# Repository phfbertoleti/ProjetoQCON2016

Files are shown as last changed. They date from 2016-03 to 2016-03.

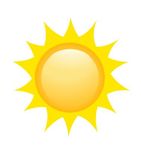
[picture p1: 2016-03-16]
Interface Web (com criptografia)/DIA.jpg

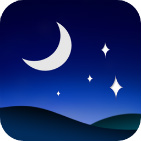
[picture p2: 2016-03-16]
Interface Web (com criptografia)/NOI.jpg

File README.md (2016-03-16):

# GitHub do projeto desenvolvido para a palestra "Embedded Systems e IoT: do bare-metal à comunicação wireless segura", realizada no evento QCON 2016.

Aqui, consta:

- Firmware completo do leitor de luminosidade (Arduino Nano v3.0)
- Firmware completo do leitor de temperatura (Arduino Duemilanove)
- Firmware completo do medidor de vazão instantânea e consumo acumulado de água (PIC)
- Script Python completo (Intel Edison)
- WebSocket que se comunica com Broker MQTT Mosquitto
- Perfis de configuração ZigBEE

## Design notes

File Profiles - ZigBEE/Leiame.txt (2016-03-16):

IMPORTANTE:

Ao carregar os perfis, não esquecer de inserir a mesma chave de encriptação nos end devices e coordenadores. Caso contrário, a comunicação encriptada não funcionará.

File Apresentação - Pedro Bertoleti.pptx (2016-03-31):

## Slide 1

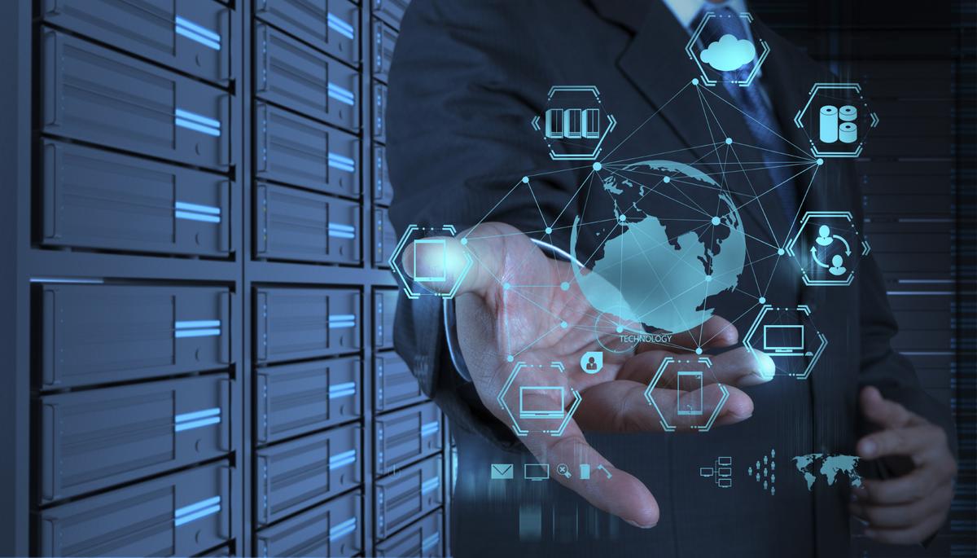
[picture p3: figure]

Embedded Systems e IoT: do bare-metal à comunicação wireless segura

Pedro Bertoleti

## Pedro Bertoleti

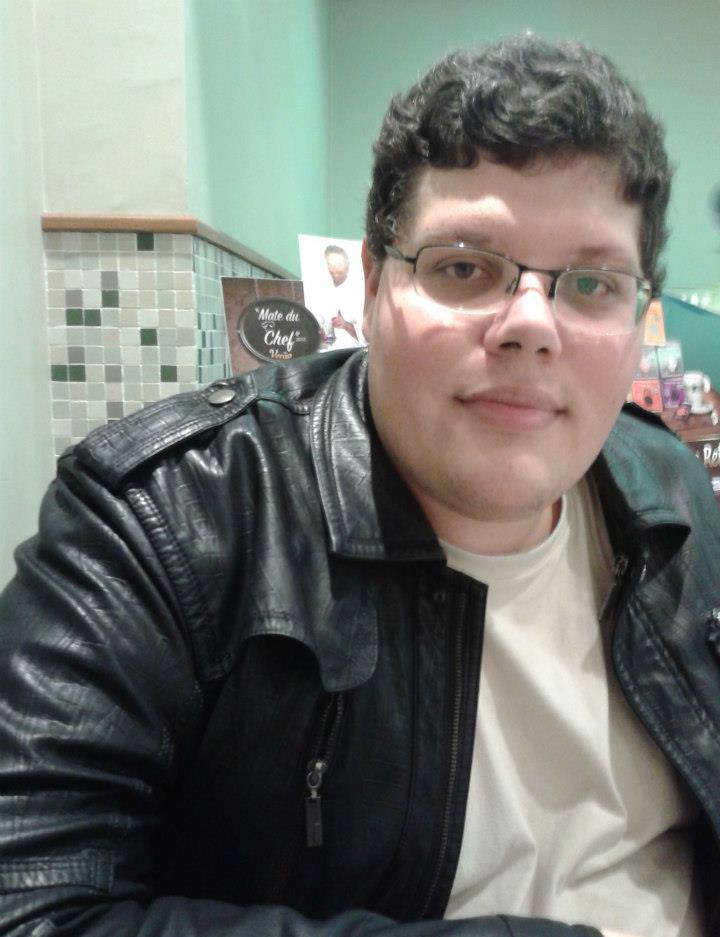
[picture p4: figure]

- Engenheiro eletricista
- Mais de 10 anos de experiência em Dev (incluindo sistemas embarcados)
- Engenheiro de firmware na Toledo do Brasil Ind. de Balanças
- Articulista do portal Embarcados (www.embarcados.com.br)

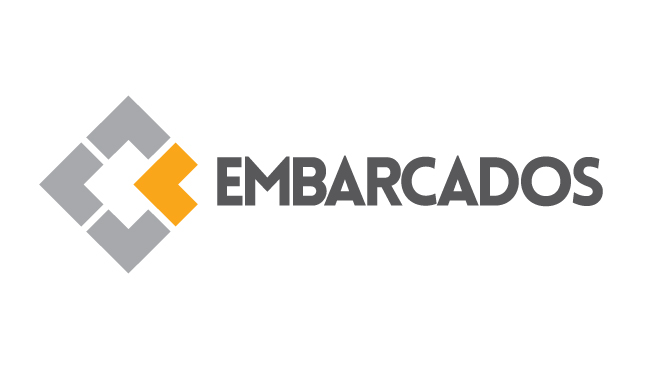
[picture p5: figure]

## Pedro Bertoleti

Áreas de interesse:
- Sistemas embarcados bare-metal
- Sensoriamento remoto
- IoT

## Tópicos desta palestra

- IoT e sensoriamento remoto
- Bare-metal no sensoriamento remoto
- O papel da Central / nó IoT
- Projeto-exemplo: arquitetura
- Projeto-exemplo: aquisição de dados
- Projeto-exemplo: publicação de dados
- Projeto-exemplo: segurança (hardware e software)
- Demonstração

## IoT

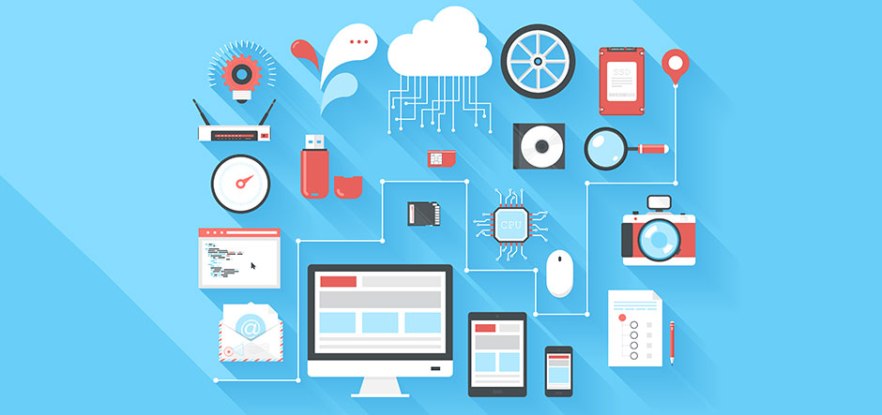
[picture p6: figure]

= tudo conectado a tudo!

## IoT

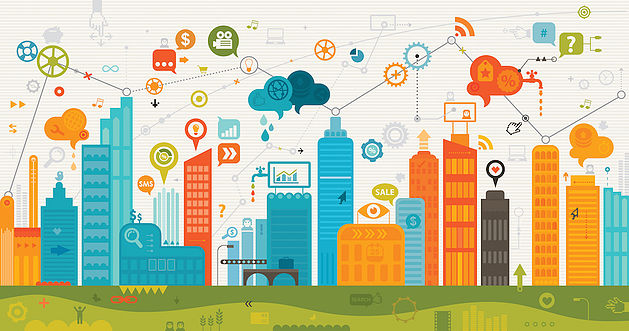
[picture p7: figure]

Então, porque não monitorar tudo, tonando nossas cidades e vidas mais inteligentes?

## IoT e sensoriamento remoto

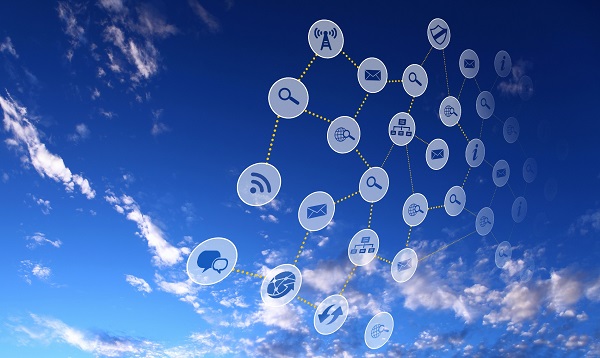
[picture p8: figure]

Para isso, é preciso sensoriar / medir tudo o que for possível!

## Caminho: Do bare-metal a IoT

Internet

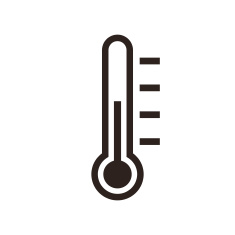
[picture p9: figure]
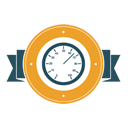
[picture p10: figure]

?

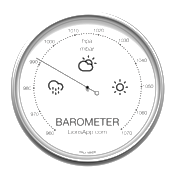
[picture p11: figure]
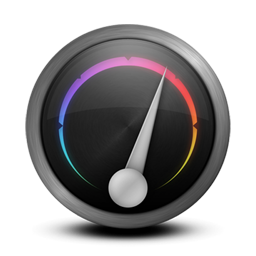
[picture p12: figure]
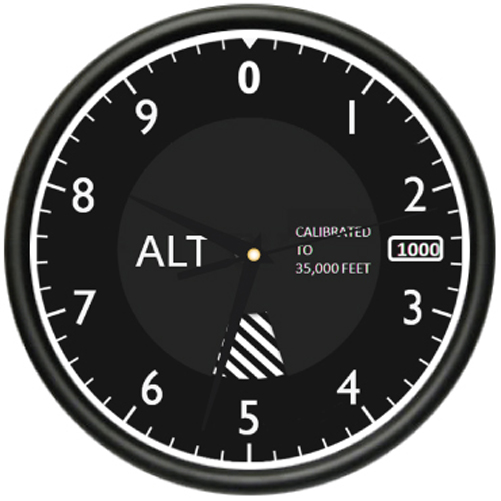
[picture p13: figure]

?

## IoT e sensoriamento remoto

Objetivos:
1) Qualidade de vida: monitorar grandezas de grande relevância financeira e ambiental

Exemplos: consumo de água, consumo de energia elétrica, poluição sonora, poluição atmosférica, etc.

2) Motivo comercial: formar uma base de dados para traçar comportamentos e tendências do consumidor

Exemplo: obter hora de pico de consumo de água e energia elétrica e suas variáveis relacionadas (temperatura ambiente, níveis de chuva, período do ano, ...) para, assim, conseguir melhor tarifar o uso destes recursos.

## IoT e sensoriamento remoto

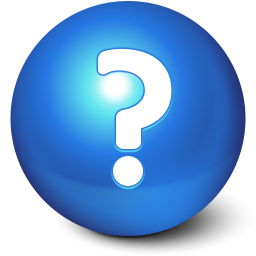
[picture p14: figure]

Como fazer?

## Bare-metal no sensoriamento remoto

Internet

Bare
Metal

?

## Bare-metal no sensoriamento remoto

O que é bare-metal?
- Modalidade de software embarcado “na raça” (sem S.O.)
- Linguagens envolvidas: C e Assembly (eventualmente C++)
- Usa o microcontrolador em baixo nível
- Permite a maior performance de um software embarcado
- Nesta camada, trabalha um desenvolvedor com maior experiência de back-end

## Bare-metal no sensoriamento remoto

Por que utilizar?
- Exige um microcontrolador com menos recursos
Permite uso de microcontroladores mais baratos (principalmente quanto a economia em memória Flash).
- Lida muito bem com grande número de interrupções sem comprometer performance final
- Maior número de proteções de software e hardware aplicáveis
Brown-out detection, Watchdog, saber o exato motivo de um reset, etc.
- Permite maior eficiência na comunicação com sensores (comunicação com periféicos de forma direta)
Funcionamento mais rápido e ágil.
- Software embarcado dedicado à sua aplicação
- Modalidade de software embarcado compatível com qualquer microcontrolador do mercado

## Bare-metal no sensoriamento remoto

Em suma:
- Permite o desenvolvimento de um software altamente robusto
- Permite uso de um hardware mais modesto
- Tem excelente performance e confiabilidade

Bare-metal: sistema projetado para ser ligado e esquecido (manutenção zero)

## O papel da Central / nó IoT

Internet

Bare
Metal

Central / Nó

## O papel da Central / nó IoT

Foi visto que:
- Fazer sensoriamento remoto é relevante tanto comercialmente quanto para aumento da qualidade de vida
- O sensoriamento começa no bare-metal
Mas, e para enviar estes dados para a Internet? O que fazer? Qual é o elo faltante?

## Central / nó IoT

- Nesta camada, o uso de um sistema operacional é bem vindo
Por baixo preço e alta disponibilidade de hardwares compatíveis e preço nulo de licença de uso, o Linux e suas distribuições mais compactas representa a maior parcela de S.O. embarcado.
- A central / nó IoT é capaz de se comunicar com sistemas bare-metal E comunicar-se com a Internet.
- É responsável por disponibilizar os dados lidos para a Internet de forma adequada.

## Central / nó IoT

- Aqui, trabalha um desenvolvedor com maior experiência de front-end
- Nesta camada, fala-se em IoT e derivados: MQTT, HTTP, Socket Connection, 3G/HSPDA/4G, etc.
- Pode ser ou não headless

## Projeto-exemplo

Internet

Consumo e fluxo de água

Luminosidade

Temperatura

Bare
Metal

Central / Nó

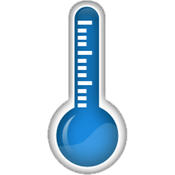
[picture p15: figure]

## Projeto-exemplo: arquitetura

Bare-metal

Consumo e fluxo de água

Bare-metal

Luminosidade

Bare-metal

Temperatura

Central-nó / IoT

Internet

Rede de sensoriamento com topologia em estrela

## Projeto-exemplo: arquitetura

- Protocolo de comunicação dos dispositivos sensores e central / nó IoT
[STX] [ENDEREÇO] [OPCODE] [TAMANHO] [CHECK-SUM] [BUFFER]
0x02 1 byte 1 byte 1 byte 1 byte Max. 255 bytes
Onde o Checksum é calculado por:
Checksum = (~SomaDeTodosOsBytes) + 1
- Os dados sempre são requisitados pela central IoT (ou seja, os módulos bare-metal funcionam sob demanda)
- Cada dispositivo de sensoriamento (bare-metal) possui um endereço

Dispositivo | Endereço
Medidor de água | 0x01
Medidor de luminosidade | 0x02
Medidor de temperatura | 0x03

Iternet

## Projeto-exemplo: arquitetura

- O sistema bare-metal comunica-se com a central IoT via ZigBEE (comunicação wireless), usando a encriptação AES 128-bit do próprio chip XBEE.
- A central IoT comunica-se com a Internet via MQTT, com payload encriptado em uma criptografia simétrica desenvolvida por mim.

Iternet

## Projeto-exemplo: aquisição de dados

- Medidor de água: calibração

Sinal do sensor de água

Conta os pulsos

Microcontrolador

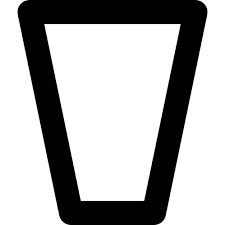
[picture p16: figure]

Volume de controle vazio

Início

Fim

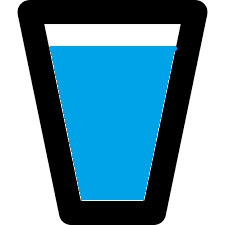
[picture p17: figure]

Iternet

Volume de controle cheio

## Projeto-exemplo: aquisição de dados

- Medidor de água: uso

Sinal do sensor de água

Microcontrolador

1- Conta os pulsos
2- Converte número de pulsos contados em volume
3- Calcula medições

## Projeto-exemplo: aquisição de dados

- Medidor de luminosidade: uso

Sinal do sensor de
luminosidade

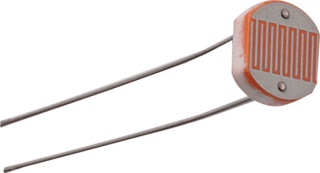
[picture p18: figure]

LDR
(sensor de luminosidade)

Microcontrolador

Converte leitura analógica em uma leitura relativa da luminosidade, capaz de dizer se é dia ou noite.

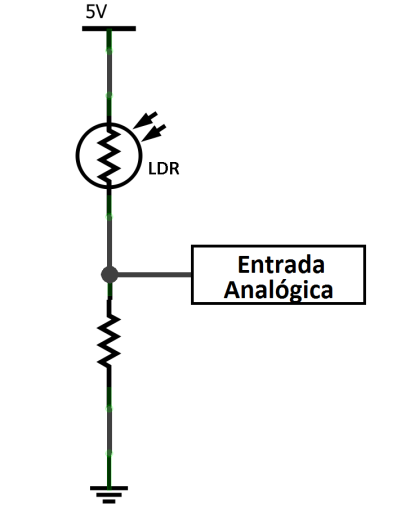
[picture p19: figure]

## Projeto-exemplo: aquisição de dados

- Medidor de temperatura: uso

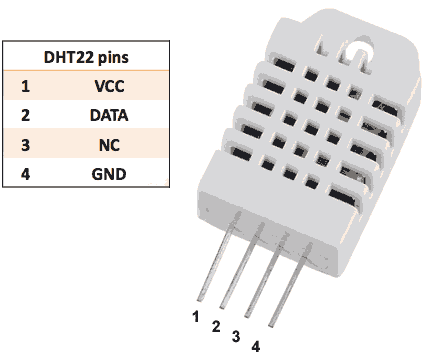
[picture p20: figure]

Protocolo de comunicação
síncrono

Microcontrolador

“Conversa” (através de um protocolo proprietário) com o sensor e obtém o valor da temperatura medida.

## Projeto-exemplo: publicação de dados

- A central IoT publica os dados para o mundo exterior via MQTT
- O payload é criptografado via criptografia proprietária
- Os dados enviados ao Broker são, necessariamente, interpretáveis somente por quem possui a chave certa de criptografia.
- No exemplo em questão, há uma maneira de modificar, quando desejado, a chave de criptografia

## Projeto-exemplo: publicação de dados

Central-nó / IoT

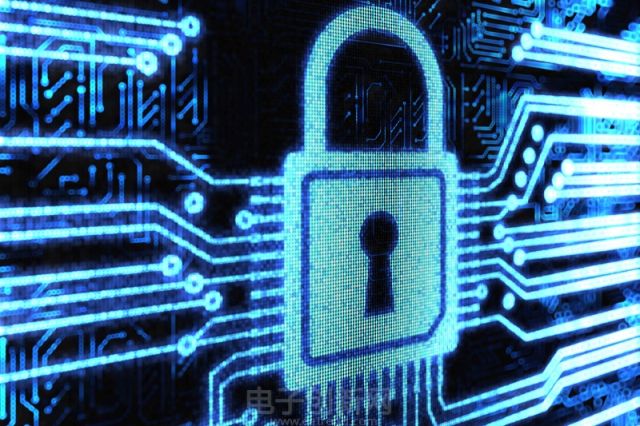
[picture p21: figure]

Criptografia simétrica proprietária

MQTT
(payload criptografado)

Internet

MQTT

Payload

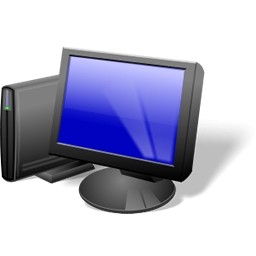
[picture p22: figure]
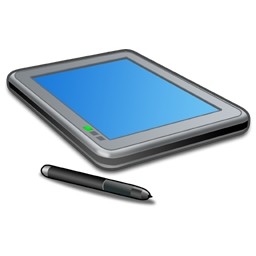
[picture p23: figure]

Dispositivos finais devem conhecer a chave para “entender” a informação

## Projeto-exemplo: segurança

Software
- Criptografia do payload (MQTT e da rede sensorial), com chave conhecida somente pelos elementos da comunicação (quem envia e quem recebe). Isso minimiza as chances de burlar a comunicação com sensores e com broker, garantindo que somente as partes interessadas terão acesso aos dados
- Os microcontroladores devem ter proteção contra leitura de código.
- A central IoT deve ter acesso restrito (atenção a senha de acesso root e sempre bloquear acesso via terminal serial / USB CDC nas placas de produção!!!)

## Projeto-exemplo: segurança

Hardware
- Não utilizar cartões SD para imagem do sistema da central-IoT. Utilizar EMC (equivalentes a memórias flash soldadas na placa).
- Após gravação dos softwares (seja no lado bare-metal ou central-IoT), colocar resina sobre os circuitos integrados principais (microcontroladores e memórias-flash)
- Somente colocar identificação de pontos de prova estitamente necessários (alimentação, por exemplo).
- Pintar a superfície dos circuitos integrados restantes (para dificultar identificação dos mesmos por alguém que queira clonar o hardware)
- Na etapa de produção, retirar todas as interfaces seriais de comunicação e debug utilizadas no desenvolvimento.
- Utilizar cases prensados para comportar as placas

## Demonstração

Acesse agora o site da demonstração!!
http://www.pjapps.qlix.com.br/QCONSP2016/

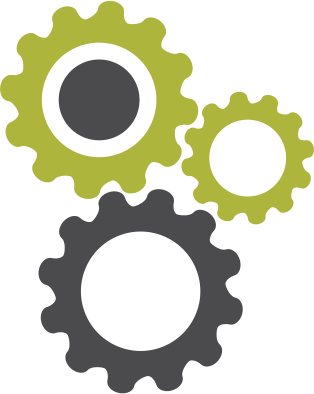
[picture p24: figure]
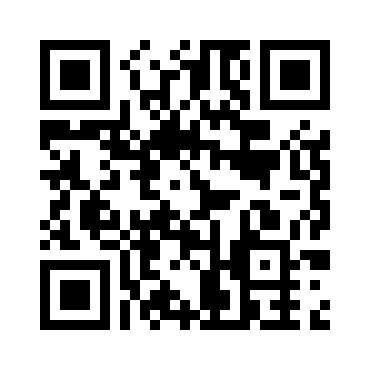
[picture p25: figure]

Iternet

## Download / colaboração do projeto

- GitHub: https (https://github.com/phfbertoleti/ProjetoQCON2016)://github.com/phfbertoleti/ProjetoQCON2016

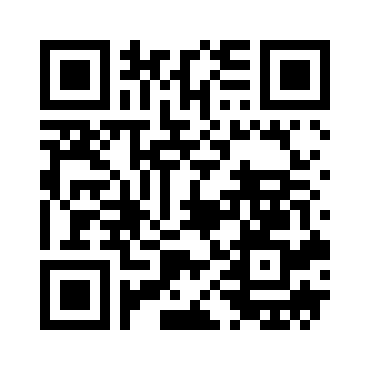
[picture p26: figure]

Iternet

## Final da palestra

Muito obrigado pela presença!

Facebook.com/pedro.bertoleti

@pedro_bertoleti

Pedro Bertoleti

In embedded we trust!

Iternet

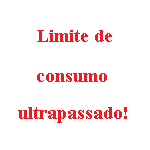
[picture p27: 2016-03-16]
Interface Web (com criptografia)/naook.png

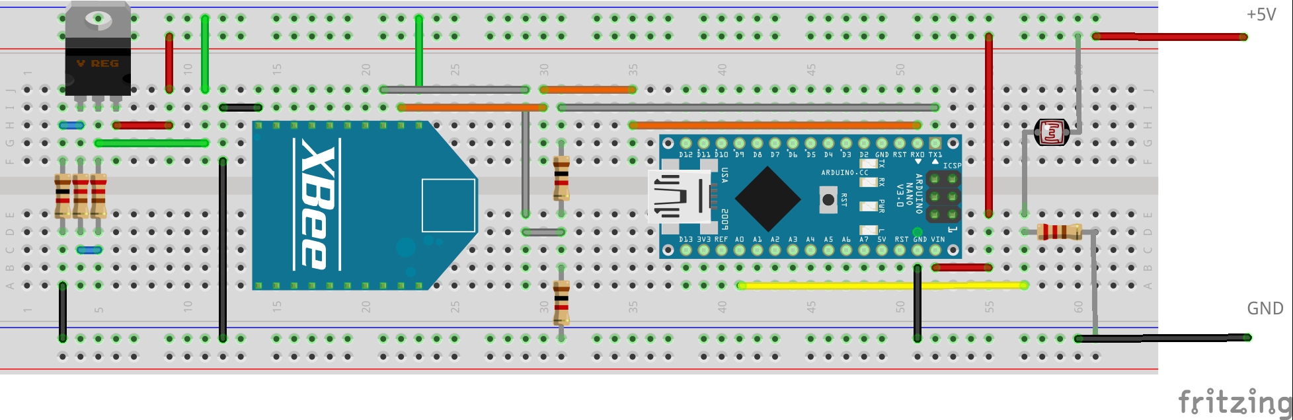
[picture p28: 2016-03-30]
Esquemáticos/Leitor de luminosidade/LeitorLuminosidade_esquematico.jpg

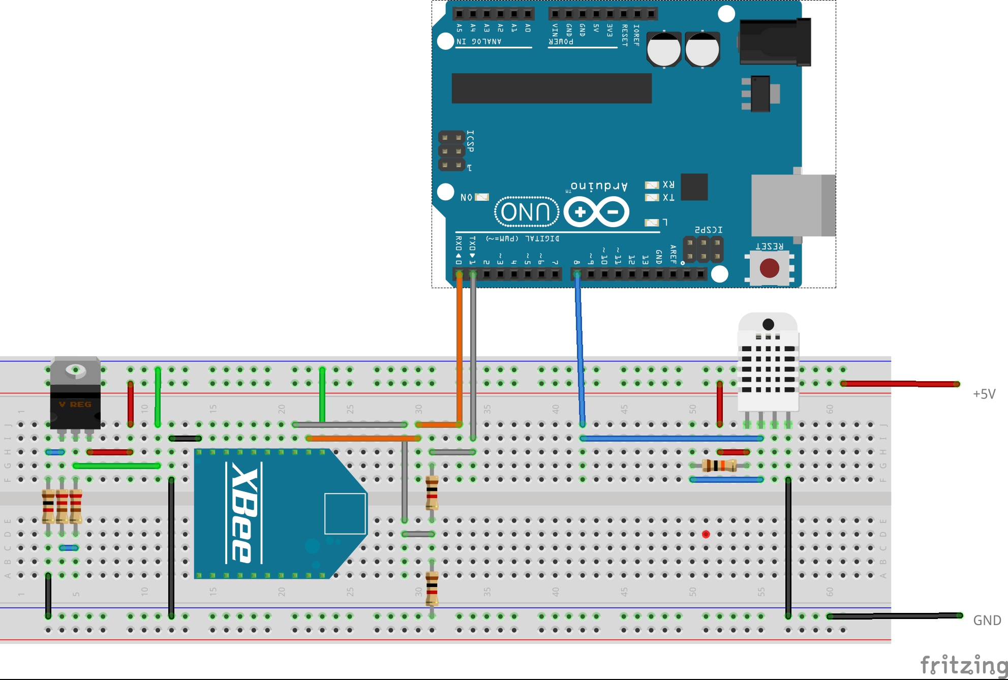
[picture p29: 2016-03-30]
Esquemáticos/Leitor de temperatura/LeitorTemperatura_esquematico.jpg

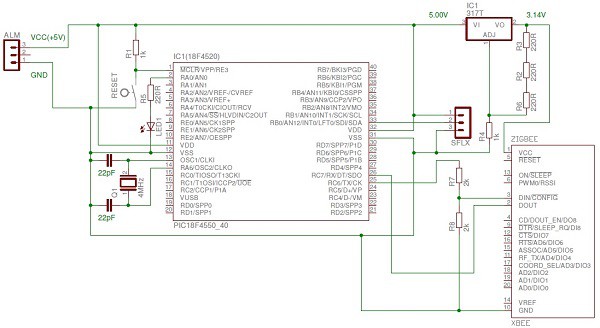
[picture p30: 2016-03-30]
Esquemáticos/Monitoramento - água/esquematico_monitoramento_agua.jpg

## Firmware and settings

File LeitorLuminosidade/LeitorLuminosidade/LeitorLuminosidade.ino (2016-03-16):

//Software do leitor de luminosidade (demonstração da palestra 
//"Embedded Systems e IoT: do bare-metal à comunicação wireless segura", 
//realizado no QCON 2016).
//Autor: Pedro Bertoleti
//Data: 02/2016
//
//IMPORTANTE: este software funciona tanto com shield ZigBEE
//            quanto com o ZigBEE ligado diretamente a serial


//----------------
// Defines gerais
//----------------
#define VERSAO               "V1.00"
#define TAMANHO_VERSAO       5
#define TAMANHO_LUMINOSIDADE 3
#define ENDERECO_BAREMETAL   2
#define SIM                  1
#define NAO                  0
#define DIA                  "DIA"
#define NOITE                "NOI"

//defines do protocolo
#define MAX_TAM_BUFFER    20
#define STX               0x02
#define CHECKSUM_OK       1
#define FALHA_CHECKSUM    0
#define RECEPCAO_OK       1
#define SEM_RECEPCAO      0

//defines dos estados
#define ESTADO_STX        1
#define ESTADO_ENDERECO   2
#define ESTADO_OPCODE     3
#define ESTADO_TAMANHO    4
#define ESTADO_CHECKSUM   5
#define ESTADO_BUFFER     6

//defines dos opcodes do protocolo (para sensor de luminosidade)
#define OPCODE_LEITURA_LUMINOSIDADE    'L'
#define OPCODE_VERSAO                  'V'

//define - tamanho da mensagem de resposta
#define TAMANHO_MAX_MSG_RESPOSTA        10 //8 bytes = STX (1 byte) + Endereço (1 byte) + Opcode (1 byte) + tamanho (1 byte) + checksum (1 byte) + Buffer (5 bytes)

//define - pino de leitura analógica
#define PINO_SENSOR_LUMINOSIDADE   0 //usa analog pin 0

//define - valor máximo que o ADC retorna na leitura
#define VALOR_MAX_ADC              1023

//----------------
// Estruturas / 
// typedefs
//----------------
typedef struct
{	
    char Endereco;
    char Opcode;
    char TamanhoMensagem;						
    char CheckSum;					
    char Buffer[MAX_TAM_BUFFER];					
} TDadosProtocoloLeitorLuminosidade;

//----------------
// variáveis globais
//----------------
TDadosProtocoloLeitorLuminosidade DadosProtocoloLeitorLuminosidade;
volatile char EstadoSerial;
char RecebeuBufferCompleto;
char DeveEnviarLuminosidade;
char DeveEnviarVersao;
char IndiceBuffer;

//----------------
// Prototypes
//----------------
void TrataMensagem(void);
void MontaEEnviaMensagem(char Opcode, char Tamanho, char * Dado);
void AguardaSTX();
void AguardaEndereco(char ByteRecebido);
void AguardaOpcode(char ByteRecebido);
void AguardaTamanho(char ByteRecebido);
void AguardaCheckSum(char ByteRecebido);
void AguardaBuffer(char ByteRecebido);
char CalculaCheckSum(void);
void MaquinaEstadoSerial(char ByteRecebido);
void EnviaLuminosidade(int LeituraADC);
void EnviaVersao(void);

//----------------
// Implementação /
//    funções
//----------------

//Aguarda STX - função da máquina de estados da comunicação serial
//parametros: byte recebido
//saida: nenhum
void AguardaSTX(char ByteRecebido)
{
    if (ByteRecebido == STX)
    {
	      memset(&DadosProtocoloLeitorLuminosidade, 0, sizeof(TDadosProtocoloLeitorLuminosidade));   //limpa dados do protocolo
	      EstadoSerial = ESTADO_ENDERECO;
    }
    else
	      EstadoSerial = ESTADO_STX;
}

//Aguarda endereço do destinatário da mensagem - função da máquina de estados da comunicação serial
//parametros: byte recebido
//saida: nenhum
void AguardaEndereco(char ByteRecebido)
{
    DadosProtocoloLeitorLuminosidade.Endereco = ByteRecebido;
	
    if (DadosProtocoloLeitorLuminosidade.Endereco == ENDERECO_BAREMETAL)
      	EstadoSerial = ESTADO_OPCODE;	
    else
	      EstadoSerial = ESTADO_STX;	
}

//Aguarda Opcode da mensagem - função da máquina de estados da comunicação serial
//parametros: byte recebido
//saida: nenhum
void AguardaOpcode(char ByteRecebido)
{
    DadosProtocoloLeitorLuminosidade.Opcode = ByteRecebido;
    EstadoSerial = ESTADO_TAMANHO;	
}

//Aguarda tamanho da mensagem - função da máquina de estados da comunicação serial
//parametros: byte recebido
//saida: nenhum
void AguardaTamanho(char ByteRecebido)
{
    if (ByteRecebido > MAX_TAM_BUFFER)
  	    EstadoSerial = ESTADO_STX;   //tamanho recebido é inválido (maior que o máximo permitido). A máquina de estados é resetada.
    else
    {	
      	DadosProtocoloLeitorLuminosidade.TamanhoMensagem = ByteRecebido;
	      EstadoSerial = ESTADO_CHECKSUM;	
    }
}

//Aguarda checksum da mensagem - função da máquina de estados da comunicação serial
//parametros: byte recebido
//saida: nenhum
void AguardaCheckSum(char ByteRecebido)
{	
    DadosProtocoloLeitorLuminosidade.CheckSum = ByteRecebido;
    
    if(DadosProtocoloLeitorLuminosidade.TamanhoMensagem > 0)
    {
        IndiceBuffer = 0;
	      EstadoSerial = ESTADO_BUFFER;
    }
    else
    {
       	RecebeuBufferCompleto = RECEPCAO_OK;
	      EstadoSerial = ESTADO_STX;
    }
}

//Aguarda buffer da mensagem - função da máquina de estados da comunicação serial
//parametros: byte recebido
//saida: nenhum
void AguardaBuffer(char ByteRecebido)
{
    if(IndiceBuffer < DadosProtocoloLeitorLuminosidade.TamanhoMensagem)
    {
	      DadosProtocoloLeitorLuminosidade.Buffer[IndiceBuffer] = ByteRecebido;
	      IndiceBuffer++;
    }
    else
    {
	      //buffer completo. Faz o tratamento da mensagem e reinicia máquina de estados
	      if (CalculaCheckSum() == CHECKSUM_OK)
            RecebeuBufferCompleto = RECEPCAO_OK;
	      else
            RecebeuBufferCompleto = SEM_RECEPCAO;
	
	      EstadoSerial = ESTADO_STX;
    }
}

//Função: checa o checksum da mensagem recebida pela UART
//parametros: nenhum
//saida: nenhum
char CalculaCheckSum(void)
{
    char CheckSumCalculado;
    char i;
	
    CheckSumCalculado = 0;
	
    for(i=0; i<DadosProtocoloLeitorLuminosidade.TamanhoMensagem; i++)
	      CheckSumCalculado = CheckSumCalculado + DadosProtocoloLeitorLuminosidade.Buffer[i];
		
    CheckSumCalculado = (~CheckSumCalculado) +1;
	
    if (CheckSumCalculado == DadosProtocoloLeitorLuminosidade.CheckSum)
	      return CHECKSUM_OK;
    else
	      return FALHA_CHECKSUM;
}


//Função que faz o gerenciamento dos estados da máquina de estado. É chamada sempre que um byte chega da serial
//parametros: byte recebido pela serial
//saida: nenhum
void MaquinaEstadoSerial(char ByteRecebido)
{
    switch(EstadoSerial)
    {
        case ESTADO_STX:
        {
            AguardaSTX(ByteRecebido);
            break; 
        }

	      case ESTADO_ENDERECO:
        {
            AguardaEndereco(ByteRecebido);
            break; 
        }
		
        case ESTADO_OPCODE:
        {
            AguardaOpcode(ByteRecebido);
            break; 
        }

        case ESTADO_TAMANHO:
        {
            AguardaTamanho(ByteRecebido);
            break; 
        }

        case ESTADO_CHECKSUM:
        {
            AguardaCheckSum(ByteRecebido);
            break; 
        }

        case ESTADO_BUFFER:
        {
            AguardaBuffer(ByteRecebido);
            break; 
        }

        
        default:   //se o estado tiver qualquer valro diferente dos esperados, significa que algo corrompeu seu valor (invasão de memória RAM). Logo a máquina de estados é reuniciada.
        {
            EstadoSerial=ESTADO_STX;
            RecebeuBufferCompleto = SEM_RECEPCAO;
            memset(&DadosProtocoloLeitorLuminosidade, 0, sizeof(TDadosProtocoloLeitorLuminosidade));   //limpa dados do protocolo
            break;
        }
    }
}

//Função: trata mensagem recebida pela UART
//parametros: nenhum
//saida: nenhum
void TrataMensagem(void)
{
    switch (DadosProtocoloLeitorLuminosidade.Opcode)
    {
        case OPCODE_LEITURA_LUMINOSIDADE:
        {
            DeveEnviarLuminosidade = SIM;
            break;
        }

        case OPCODE_VERSAO:
        {
            DeveEnviarVersao = SIM;
            break;
        }

        default:
        {
            DeveEnviarLuminosidade = NAO;
            DeveEnviarVersao = NAO;
            RecebeuBufferCompleto = SEM_RECEPCAO;
            EstadoSerial = ESTADO_STX;

            //limpa dados do protocolo 
            memset(&DadosProtocoloLeitorLuminosidade, 0, sizeof(TDadosProtocoloLeitorLuminosidade));  
        }
    }    
}

//Função: formata e envia a mensagem (em resposta à solicitação)
//parametros: opcode, tamanho, ponteiro pro dado ascii
//saida: nenhum
void MontaEEnviaMensagem(char Opcode, char Tamanho, char * Dado)
{
    char BufferAscii[TAMANHO_MAX_MSG_RESPOSTA];
    char CheckSumMsg;
    char i;

    CheckSumMsg = 0;

    //monta mensagem de resposta à solicitação de consumo
    memset(BufferAscii,0,TAMANHO_MAX_MSG_RESPOSTA);
    BufferAscii[0]=STX;
    BufferAscii[1]=ENDERECO_BAREMETAL;
    BufferAscii[2]=Opcode; 
    BufferAscii[3]=Tamanho; 

    if (Tamanho)
    {
        for(i=0; i<Tamanho; i++)
        {
            CheckSumMsg = CheckSumMsg + Dado[i];
            BufferAscii[5+i]=Dado[i];
        }
    }
    
    CheckSumMsg = (~CheckSumMsg) + 1;
    BufferAscii[4]=CheckSumMsg;

   //envio da mensagem
   for (i=0;i<sizeof(BufferAscii);i++)
      Serial.write(BufferAscii[i]);
} 

//Função: envia para a serial a luminosidade
//parametros: nenhum
//saida: nenhum
void EnviaLuminosidade(int LeituraADC)
{    
    int PorcentagemLuminosidade;
    char LeituraDia[]=DIA;
    char LeituraNoite[]=NOITE;
    
    PorcentagemLuminosidade = LeituraADC;

    if (PorcentagemLuminosidade < 375)
        MontaEEnviaMensagem(OPCODE_LEITURA_LUMINOSIDADE, TAMANHO_LUMINOSIDADE, (char *)LeituraNoite);   
    else
        MontaEEnviaMensagem(OPCODE_LEITURA_LUMINOSIDADE, TAMANHO_LUMINOSIDADE, (char *)LeituraDia); 

}

//Função: envia para a serial a versao do firmware
//parametros: nenhum
//saida: nenhum
void EnviaVersao(void)
{  
   char VersaoFW[]=VERSAO;

   MontaEEnviaMensagem(OPCODE_VERSAO, TAMANHO_VERSAO, (char *)VersaoFW);
}


void setup() 
{
    //inicializa variáveis de controle de envio de luminosidade
    RecebeuBufferCompleto = SEM_RECEPCAO;
    DeveEnviarLuminosidade = NAO;
    DeveEnviarVersao = NAO;
  
    //inicia comunicação serial a 9600 bauds 
    Serial.begin(9600);
}

void loop() 
{
    int LeituraADC;
    char ByteLido;

    if (Serial.available())
    {
        ByteLido = Serial.read();
        MaquinaEstadoSerial(ByteLido);
    }
        
    if (RecebeuBufferCompleto == RECEPCAO_OK)
    {
        TrataMensagem();
        RecebeuBufferCompleto = SEM_RECEPCAO;
    }
    
    if (DeveEnviarLuminosidade == SIM)    
    {
        LeituraADC = analogRead(PINO_SENSOR_LUMINOSIDADE);
        EnviaLuminosidade(LeituraADC);
        DeveEnviarLuminosidade = NAO; 
    }
    
    if (DeveEnviarVersao == SIM)    
    {
        EnviaVersao();
        DeveEnviarVersao = NAO; 
    }    
}

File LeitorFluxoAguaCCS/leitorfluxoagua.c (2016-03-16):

//Firmware leitor de fluxo de água (demonstração da palestra "Embedded Systems e IoT: do bare-metal à comunicação wireless segura", realizado no QCON 2016)
//Autor: Pedro Bertoleti
//Data: 02/2016
//IMPORTANTE: deve ser compilado com o compilador CCS v4.093


#include <18F4520.h>
#include "HeaderLeitor.h"
#use delay(clock=4000000) 	//Clock de 4MHz (clock útil de 1MHz)
#fuses WDT128,HS,PUT,NOPROTECT
#use rs232(baud=9600,parity=N,xmit=PIN_C6,rcv=PIN_C7,bits=8,ERRORS)
#priority INT_TIMER1, INT_EXT, INT_RDA  //ordem de prioridad das interrupções (ordem decrescente de prioridade)

//defines gerais: 

//saída (breathing light)
#define BREATHING_LIGHT             PIN_A0
#define TAMANHO_MSG_RESPOSTA        sizeof(TDadosProtocoloLeitorAgua) + 2
#define TAMANHO_CHAVE_EEPROM        sizeof(ChaveEEPROM)
#define TAMANHO_VERSAO              sizeof(VersaoEquipamento)-1
#define TAMANHO_VAZAO_ASCII         6
#define TAMANHO_CONSUMO_ASCII       6

//prototypes
void ConfigInterrupcaoEXT(void);
void ConfigInterrupcaoUART(void);
void ConfigTimer1(void);
void TrataMensagem(void);
void LeConsumoAcumulado(void);
void LeCalibracaoSensor(void);
void SalvaCalibracaoSensor(void);
void ResetConsumoAcumulado(void);
void ResetCalibracaoSensor(void);
char VerificaChaveEEPROM(char EnderecoInicialChave);
void MontaEEnviaMensagem(char Opcode, char Tamanho, char * Dado);
void MontaEEnviaMensagemNula(char Opcode);
void AguardaSTX();
void AguardaEndereco(char ByteRecebido);
void AguardaOpcode(char ByteRecebido);
void AguardaTamanho(char ByteRecebido);
void AguardaCheckSum(char ByteRecebido);
void AguardaBuffer(char ByteRecebido);
char CalculaCheckSum(void);
void MaquinaEstadoSerial(char ByteRecebido);


//tratamento da interrupção externa
#int_EXT 
void  EXT_isr(void) 
{ 
	ContadorPulsos++;    
} 

//tratamento da interrupção serial
#INT_RDA
void serial_isr()
{ 
    char ByteLido;
    ByteLido = getc();
    MaquinaEstadoSerial(ByteLido);
} 

//tratamento da interrupção de timer
#INT_TIMER1
void TrataTimer1()
{
	ContadorIntTimer++;

    if (ContadorIntTimer < 5)   //cada "tick" do timer1 tem 0,2s. Logo, 5 "tiks" equivalem a 1 segundo
    {
        set_timer1(15536);
		return;
	}

	if (EstaEmModoCalibracao == SIM)  //se o equipamento está em modo calibração, nada deve ser feito aqui
	{
		set_timer1(15536);
		return;
	}
	
	if (PulsosPorLitro == 0) //não há calibração do sensor realizada. Nenhum calculo é feito
	{
		VazaoCalculada = 0;	
		memset(VazaoAscii,0,sizeof(VazaoAscii));
    	sprintf(VazaoAscii,"%6.2f",VazaoCalculada);

		ConsumoCalculado = 0;
		memset(ConsumoAscii,0,sizeof(ConsumoAscii));
    	sprintf(ConsumoAscii,"%6.2f",ConsumoCalculado);

		set_timer1(15536);
		return;
	}
	
    //1 segundo se passou
    ContadorIntTimer=0;
    TempoSalvamentoConsumo++;

   	//deliga todas interrupções
    disable_interrupts(INT_RDA);
    disable_interrupts(INT_EXT);

    //calcula vazão em l/h
    FrequenciaCalculada = ContadorPulsos;
	VazaoCalculada = 0;

    /*
                Pulsos                    Volume     Tempo
               	PulsosPorLitro      ---     1l   --- 1s
				FrequenciaCalculada ---      x   --- 1s 
                
				x = FrequenciaCalculada / PulsosPorLitro
				
    */
    VazaoCalculada = (float)((float)FrequenciaCalculada / (float)PulsosPorLitro);  //l/s
	
    ConsumoCalculado = ConsumoCalculado + VazaoCalculada;    //contabiliza consumo deste periodo
	VazaoCalculada = VazaoCalculada*3600.0;   //l/h

	memset(VazaoAscii,0,sizeof(VazaoAscii));
    sprintf(VazaoAscii,"%6.2f",VazaoCalculada);

    //calcula consumo e o formata para ascii
    memset(ConsumoAscii,0,sizeof(ConsumoAscii));
    sprintf(ConsumoAscii,"%6.2f",ConsumoCalculado);
	
    //verifica se deve salvar na eeprom o consumo total
    if (TempoSalvamentoConsumo >= TEMPO_SALVAMENTO_CONSUMO_SEGUNDOS)  
		DeveGravarConsumo = SIM;
	
    //troca o estado da saída do breathing light
	output_toggle(BREATHING_LIGHT);
     
    //configura timer e religa interrupções	
    set_timer1(15536);
    ConfigInterrupcaoUART();
    ConfigInterrupcaoEXT();	
}

//Aguarda STX - função da máquina de estados da comunicação serial
//parametros: byte recebido
//saida: nenhum
void AguardaSTX(char ByteRecebido)
{
    if (ByteRecebido == STX)
	{
		memset(&DadosProtocoloLeitorAgua, 0, sizeof(TDadosProtocoloLeitorAgua));   //limpa dados do protocolo
		EstadoSerial = ESTADO_ENDERECO;
	}
	else
		EstadoSerial = ESTADO_STX;
}

//Aguarda endereço do destinatário da mensagem - função da máquina de estados da comunicação serial
//parametros: byte recebido
//saida: nenhum
void AguardaEndereco(char ByteRecebido)
{
    DadosProtocoloLeitorAgua.Endereco = ByteRecebido;
	
	if (DadosProtocoloLeitorAgua.Endereco == ENDERECO_BAREMETAL)
		EstadoSerial = ESTADO_OPCODE;	
	else
		EstadoSerial = ESTADO_STX;	
}

//Aguarda Opcode da mensagem - função da máquina de estados da comunicação serial
//parametros: byte recebido
//saida: nenhum
void AguardaOpcode(char ByteRecebido)
{
    DadosProtocoloLeitorAgua.Opcode = ByteRecebido;
	EstadoSerial = ESTADO_TAMANHO;	
}

//Aguarda tamanho da mensagem - função da máquina de estados da comunicação serial
//parametros: byte recebido
//saida: nenhum
void AguardaTamanho(char ByteRecebido)
{
	if (ByteRecebido > MAX_TAM_BUFFER)
		EstadoSerial = ESTADO_STX;   //tamanho recebido é inválido (maior que o máximo permitido). A máquina de estados é resetada.
	else
	{	
		DadosProtocoloLeitorAgua.TamanhoMensagem = ByteRecebido;
		EstadoSerial = ESTADO_CHECKSUM;	
	}
}

//Aguarda checksum da mensagem - função da máquina de estados da comunicação serial
//parametros: byte recebido
//saida: nenhum
void AguardaCheckSum(char ByteRecebido)
{	
    DadosProtocoloLeitorAgua.CheckSum = ByteRecebido;
	if(DadosProtocoloLeitorAgua.TamanhoMensagem > 0)
	{
		IndiceBuffer = 0;
		EstadoSerial = ESTADO_BUFFER;
	}
	else
	{
		RecebeuBufferCompleto = 1;
		EstadoSerial = ESTADO_STX;
	}
}

//Aguarda buffer da mensagem - função da máquina de estados da comunicação serial
//parametros: byte recebido
//saida: nenhum
void AguardaBuffer(char ByteRecebido)
{
    if(IndiceBuffer < DadosProtocoloLeitorAgua.TamanhoMensagem)
	{
		DadosProtocoloLeitorAgua.Buffer[IndiceBuffer] = ByteRecebido;
		IndiceBuffer++;
	}
	else
	{
		//buffer completo. Faz o tratamento da mensagem e reinicia máquina de estados
		if (CalculaCheckSum() == CHECKSUM_OK)
			RecebeuBufferCompleto = RECEPCAO_OK;
		else
            RecebeuBufferCompleto = SEM_RECEPCAO;
	
		EstadoSerial = ESTADO_STX;
	}
}

//Checa o checksum da mensagem recebida pela UART
//parametros: nenhum
//saida: nenhum
char CalculaCheckSum(void)
{
	char CheckSumCalculado;
	char i;
	
	CheckSumCalculado = 0;
	
	for(i=0; i<DadosProtocoloLeitorAgua.TamanhoMensagem; i++)
		CheckSumCalculado = CheckSumCalculado + DadosProtocoloLeitorAgua.Buffer[i];
		
	CheckSumCalculado = (~CheckSumCalculado) +1;
	
	if (CheckSumCalculado == DadosProtocoloLeitorAgua.CheckSum)
		return CHECKSUM_OK;
	else
		return FALHA_CHECKSUM;
}
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

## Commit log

2016-03-16 Demonstração
    Sistema completo (firmwares/bare-metal, Linux embarcado e websocket para
    comunicação com Broker)
    [HeaderLeitor.h, LeitorLuminosidade.ino, LeitorTemperatura.ino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]
2016-03-30 Esquemáticos
    Esquemáticos do projeto
    [LeitorLuminosidade.fzz, LeitorTemperatura.fzz]
